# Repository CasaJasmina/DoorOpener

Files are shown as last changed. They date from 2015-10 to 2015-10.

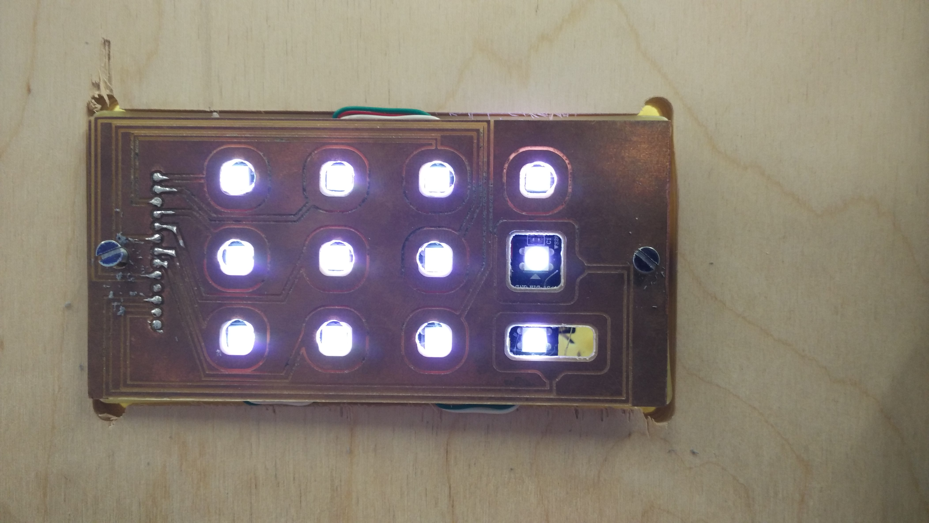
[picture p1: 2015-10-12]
pics/capacitive_board.jpg

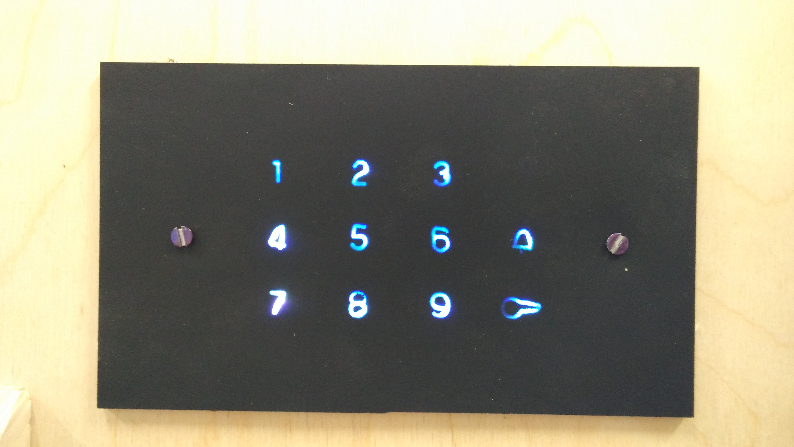
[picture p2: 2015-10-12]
pics/front plate.jpg

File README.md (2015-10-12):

# Door Opener
A combination of a capacitive keypad/doorbell and a hacked lockitron.
At the moment there is a wired connection between the two parts of the project allowing the opening of the door when the right combination is pressed.

## The keypad




The keypad is based on Arduino YUN.
It uses MPR1221 for capacitive touch detection and addressable RGB led to provide feedbacks to the user.
find more inside the keypad folder

## The lockitron




To open the door a old model of lockitron was hacked. You can get the mechanical parts from Adafruit.
A custom PCB based on ESP8266 was designed and milled.

## TODO
- connect the system to Arduino Cloud

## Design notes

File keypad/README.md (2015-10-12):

# DoorOpener
A combination of a capacitive keypad/doorbell and a hacked lockitron

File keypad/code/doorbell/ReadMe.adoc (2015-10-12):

:Project: Project Name
:Author: Author Name
:Email: author-email@example.com
:Date: 01/01/2000
:Revision: version
:License:

_Add some other information about your project!_

=== Installation
Please describe the steps to install this project.

For example:

1. Open this file
2. Edit as you like
3. Release to the World!

=== Folder {Name} structure

....
 sketch123                => Arduino sketch folder
  ├── sketch123.ino       => main arduino file
  ├── schematics.png      => (optional) an image of the required schematics
  ├── layout.png          => (optional) an image of the layout
  └── ReadMe.adoc         => this file
....

....
 sketchABC                => Linux sketch folder
  ├── sketch123.ino       => main linux file
  ├── schematics.png      => (optional) an image of the required schematics
  ├── layout.png          => (optional) an image of the layout
  └── ReadMe.adoc         => instructions for linux file
....

=== License
This project is released under a {License} License.

=== Contributing
To contribute to thei project please contact {Author} <{Email}>

=== BOM
Add the bill of the material you need for this project.

=== Help
This document is written in the _AsciiDoc_ format, a markup language to describe documents. 
If you need help you can search the http://www.methods.co.nz/asciidoc[AsciiDoc homepage]
or consult the http://powerman.name/doc/asciidoc[AsciiDoc cheatsheet]

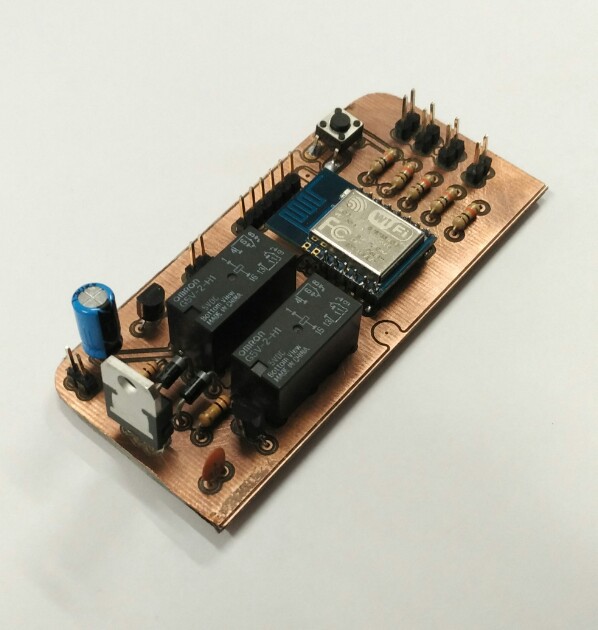
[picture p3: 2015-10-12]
pics/esp_lockitron_board.jpg

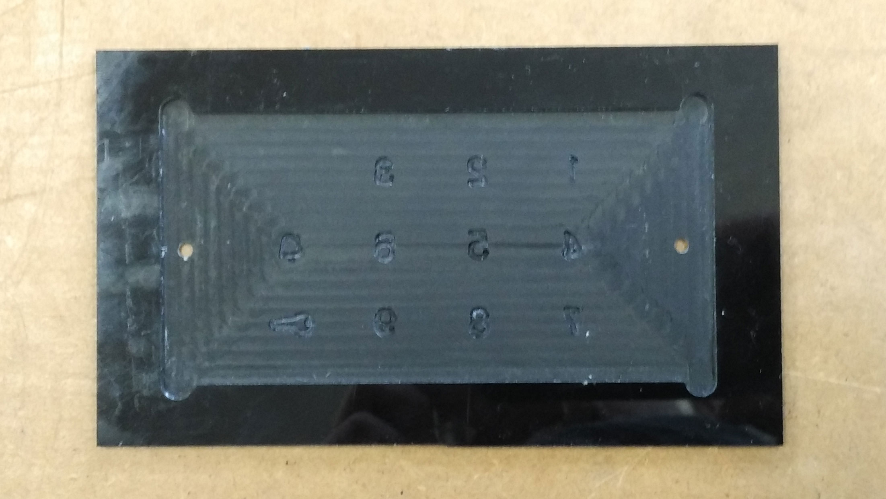
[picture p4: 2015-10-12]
pics/front_plate_back.jpg

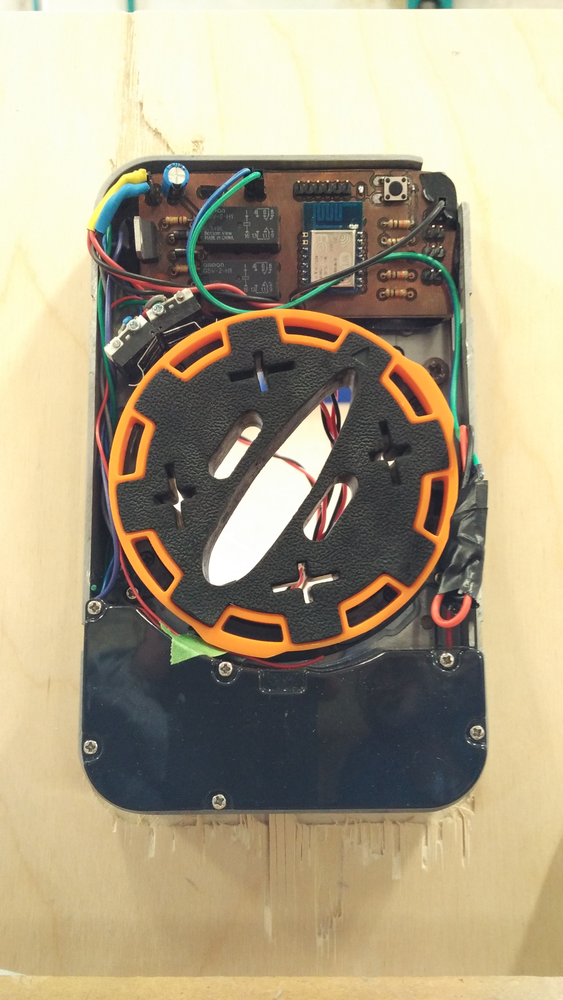
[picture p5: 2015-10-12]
pics/lockitron.jpg

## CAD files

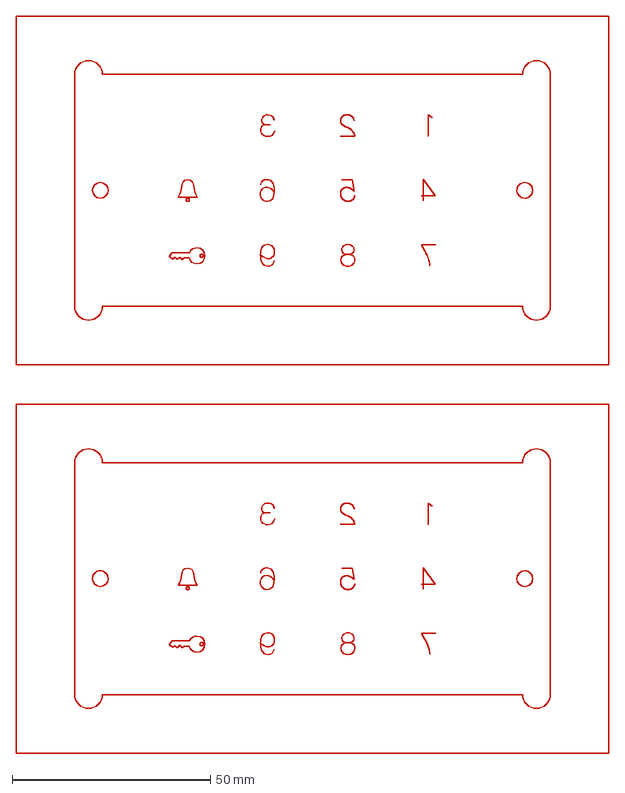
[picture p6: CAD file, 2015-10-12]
keypad/parts/front plate.dxf
149.5 x 186.0 mm

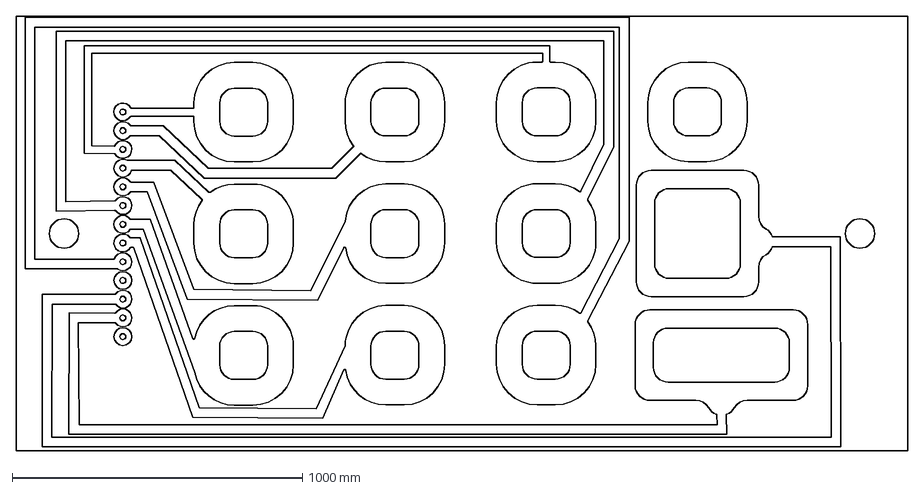
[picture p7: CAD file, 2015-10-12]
keypad/parts/capacitive_pcb.dxf
3073.4 x 1498.6 mm

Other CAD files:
keypad/parts/keypad.3dm

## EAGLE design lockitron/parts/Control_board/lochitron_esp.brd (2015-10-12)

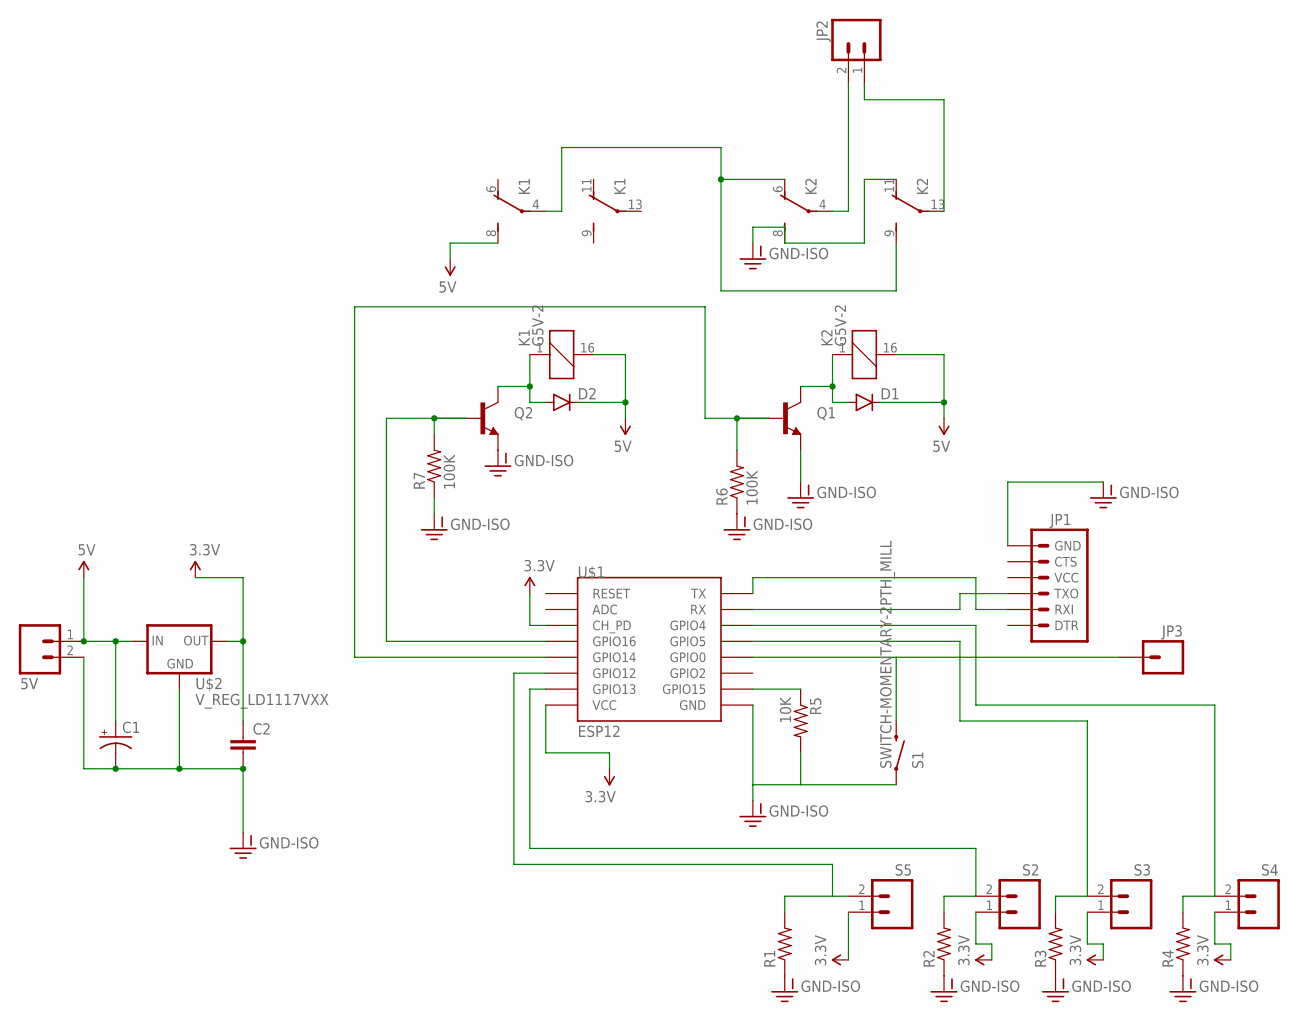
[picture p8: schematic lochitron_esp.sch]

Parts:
5V: M02LOCK_LONGPADS; 1X02_LOCK_LONGPADS
C1: 100UF-25V-20%(PTH); CPOL-RADIAL-100UF-25V
C2: 0.1UF-50V-20%(PTH)KIT-EZ; CAP-PTH-SMALL-KIT
D1, D2: DIODE1N4148; DIODE-1N4148
JP1: ARDUINO_SERIAL_PROGRAMLONGPADS; 1X06_LONGPADS
JP2: M02LOCK_LONGPADS; 1X02_LOCK_LONGPADS
JP3: M01PTH_LONGPAD; 1X01_LONGPAD
K1, K2: G5V-2
Q1, Q2: TRANSISTOR_NPNBC547; TO-92-AMMO
R1, R2, R3, R4: RESISTORAXIAL-0.3; AXIAL-0.3
R5: 10K; AXIAL-0.3
R6, R7: 100K; AXIAL-0.3
S1: SWITCH-MOMENTARY-2PTH_MILL; TACTILE-PTH
S2, S3, S4, S5: M02LOCK_LONGPADS; 1X02_LOCK_LONGPADS
U$1: ESP12
U$2: V_REG_LD1117VXX; 78XXL

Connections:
3.3V: C2.1, S2.1, S3.1, S4.1, S5.1, U$1.CH_PD, U$1.VCC, U$2.GND (OUT)
5V: 5V.1, C1.1 (+), D1.C, D2.C, K1.8 (S), K1.16 (2), K2.16 (2), U$2.OUT (IN)
GND-ISO: 5V.2, C1.2 (-), C2.2, JP1.6 (GND), K2.8 (S), K2.11 (O), Q1.3 (E), Q2.3 (E), R1.P$1 (1), R2.P$1 (1), R3.P$1 (1), R4.P$1 (1), R5.P$2 (2), R6.P$1 (1), R7.P$1 (1), S1.1, U$1.GND, U$2.IN (GND)
unnamed: D2.A, K1.1, Q2.1 (C)
unnamed: D1.A, K2.1, Q1.1 (C)
unnamed: JP3.1, S1.3 (2), U$1.GPIO0
unnamed: JP1.3 (TXO), U$1.RX
unnamed: JP1.2 (RXI), U$1.TX
unnamed: K1.4, K2.6 (O), K2.9 (S)
unnamed: R5.P$1 (1), U$1.GPIO15
unnamed: R2.P$2 (2), S2.2, U$1.GPIO13
unnamed: Q2.2 (B), R7.P$2 (2), U$1.GPIO16
unnamed: R4.P$2 (2), S4.2, U$1.GPIO4
unnamed: R3.P$2 (2), S3.2, U$1.GPIO5
unnamed: R1.P$2 (2), S5.2, U$1.GPIO12
unnamed: JP2.2, K2.4
unnamed: JP2.1, K2.13
unnamed: Q1.2 (B), R6.P$2 (2), U$1.GPIO14

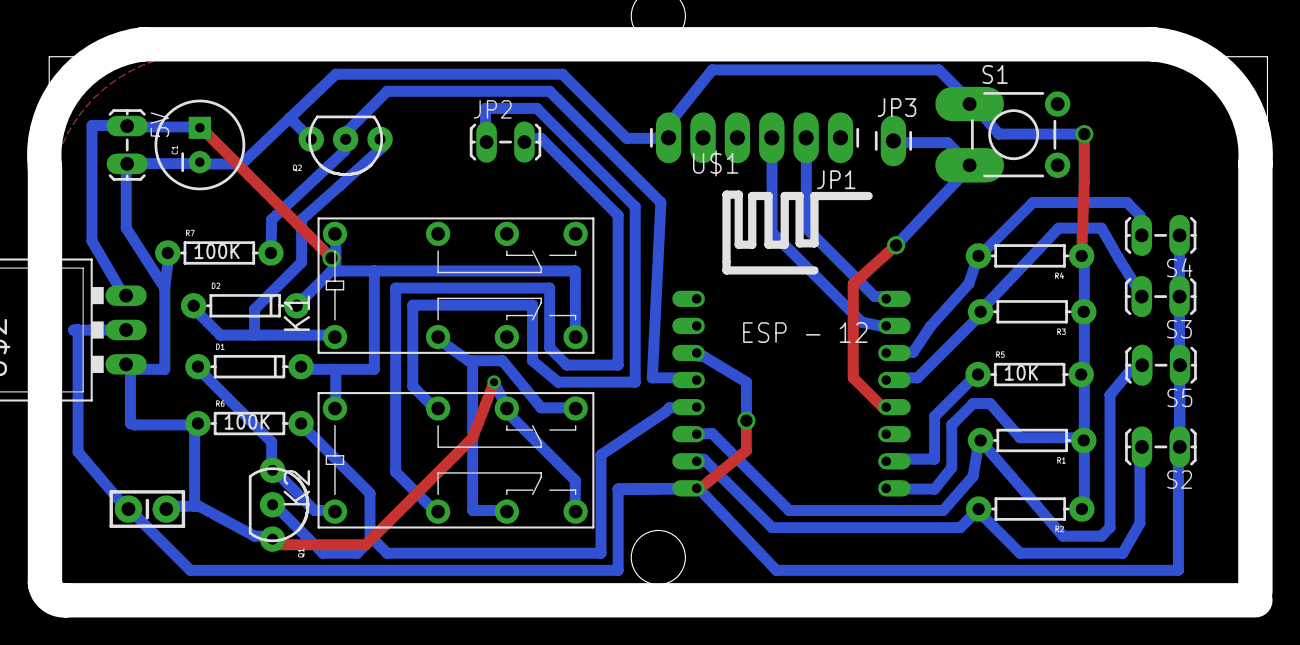
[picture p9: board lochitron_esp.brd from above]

Board: 2 copper layers, 90.4 x 41.1 mm, 26 parts (0 on the bottom side), 18 nets.

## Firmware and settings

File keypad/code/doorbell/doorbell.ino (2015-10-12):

#include <Wire.h>
#include <MPR121.h>

// You can have up to 4 on one i2c bus but one is enough for testing!

#include "touch.h"

// Keeps track of the last pins touched
// so we know when buttons are 'released'


#include <Adafruit_NeoPixel.h>
#ifdef __AVR__
#include <avr/power.h>
#endif
#define PIN            9
#define NUMPIXELS      12

#define numElectrodes 12

#include "lights.h"
#include "code.h"

int keylength = 4;
int keypressed[4];

int dooropener = 13;

void setup() {
  Serial.begin(9600);
  pinMode (dooropener, OUTPUT);

  Wire.begin();

  if (!MPR121.begin(0x5A)) {
    Serial.println("error setting up MPR121");
    switch (MPR121.getError()) {
      case NO_ERROR:
        Serial.println("no error");
        break;
      case ADDRESS_UNKNOWN:
        Serial.println("incorrect address");
        break;
      case READBACK_FAIL:
        Serial.println("readback failure");
        break;
      case OVERCURRENT_FLAG:
        Serial.println("overcurrent on REXT pin");
        break;
      case OUT_OF_RANGE:
        Serial.println("electrode out of range");
        break;
      case NOT_INITED:
        Serial.println("not initialised");
        break;
      default:
        Serial.println("unknown error");
        break;
    }
    while (1);
  }




  // pin 4 is the MPR121 interrupt on the Bare Touch Board
  MPR121.setInterruptPin(4);

  // this is the touch threshold - setting it low makes it more like a proximity trigger
  // default value is 40 for touch
  MPR121.setTouchThreshold(10);

  // this is the release threshold - must ALWAYS be smaller than the touch threshold
  // default value is 20 for touch
  MPR121.setReleaseThreshold(8);

  // initial data update
  MPR121.updateTouchData();


  pixels.begin(); // This initializes the NeoPixel library.
  resetPixels();
}

void loop() {
  int newTouch = checkTouchReleased() + 1;
  if (newTouch != 0) {
    Serial.println(newTouch);
    turnOnPixel(newTouch - 1);
    turnOffPixel(newTouch - 1);


    for (int i = 0; i < 4; i++) {
      if (keypressed[i] == 0) {
        keypressed[i] = newTouch;
        if (i == keylength - 1) {
          //here I verify the combination
          Serial.println("verifico Combinazione");
          if (checkCombination()) {
            Serial.println("open the door");
            showGood();
            openTheDoor();

          } else {
            Serial.println("error");
            showError();
          }
          resetKeys();
          resetPixels();
        }
        break;
      }
    }

    if (keypressed)
      for (int i = 0; i < 4; i++) {
        Serial.print(keypressed[i]);
        Serial.print(" ");
      }
    Serial.println();
  }
}

boolean checkCombination() {
  for (int i = 0; i < keylength; i++) {
    if (keypressed[i] != combination[i]) {
      return (false);
    }
  }
  return (true);
}

boolean resetKeys() {
  for (int i = 0; i < keylength; i++) {
    keypressed[i] = 0;
  }
}

void openTheDoor() {
  digitalWrite(dooropener, HIGH);
  delay(1000);
  digitalWrite(dooropener, LOW);

}

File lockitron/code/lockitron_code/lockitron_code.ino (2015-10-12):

/*
  Blink
  Turns on an LED on for one second, then off for one second, repeatedly.

  Most Arduinos have an on-board LED you can control. On the Uno and
  Leonardo, it is attached to digital pin 13. If you're unsure what
  pin the on-board LED is connected to on your Arduino model, check
  the documentation at http://www.arduino.cc

  This example code is in the public domain.

  modified 8 May 2014
  by Scott Fitzgerald
 */

int motorON = 16;
int motorDir = 14;


int es1 = 13;
int es2 = 4;
int es3 = 5;

int openDoorCmd = 0;


// the setup function runs once when you press reset or power the board
void setup() {
  // initialize digital pin 13 as an output.

  pinMode(motorON, OUTPUT);
  pinMode(motorDir, OUTPUT);

  pinMode (es1, INPUT);
  pinMode (es2, INPUT);
  pinMode (es3, INPUT);

  pinMode (openDoorCmd, INPUT);


  Serial.begin (9600);
}


// the loop function runs over and over again forever
void loop() {

  if (digitalRead(es3) == 1) {
    Serial.println("I'm opening the door");
    turnLeft();
    delay(2000);
    turnRight();
    delay(2000);
    stopMotor();
  }
}


void turnRight() {
  digitalWrite(motorON, HIGH);   // turn the LED on (HIGH is the voltage level)
  digitalWrite(motorDir, LOW);
}

void turnLeft() {
  digitalWrite(motorON, HIGH);   // turn the LED on (HIGH is the voltage level)
  digitalWrite(motorDir, HIGH);
}

void stopMotor() {
  digitalWrite(motorON, LOW);   // turn the LED on (HIGH is the voltage level)
  digitalWrite(motorDir, LOW);
}

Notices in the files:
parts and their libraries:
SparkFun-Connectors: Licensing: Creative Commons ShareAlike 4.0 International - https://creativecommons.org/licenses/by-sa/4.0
